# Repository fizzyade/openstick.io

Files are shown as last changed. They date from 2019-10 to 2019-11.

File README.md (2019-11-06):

[uri_license]: https://www.gnu.org/licenses/gpl-3.0.en.html
[uri_license_image]: https://img.shields.io/badge/License-GPLv3-blue.svg

[][uri_license]

# openstick.io
openstick.io is an open source hardware &amp; software project for a USB memory stick.

## About

This project provides an open source hardware design & firmware for a reference implementation of a USB memory stick.  The idea behind this is that extra functionality can be
added to the design, adding encryption, cloning of a stick or more specialised functionality may be added easily.

The actual storage is provided by an on-board Micro SD card, to the host it will look just like a normal memory stick and not a SD card reader.

## Repository Contents

* **/hardware** - KiCad schematic and PCB layout source files.
* **/firmware** - The firmware for the [STM32F070F6Px](https://www.st.com/en/microcontrollers-microprocessors/stm32f070f6.html) microcontroller.

## Required Tools

* **[STM32CubeIDE](https://https://www.st.com/en/development-tools/stm32cubeide.html)** for firmware development.
* **[KiCad](http://kicad-pcb.org/)** for hardware design.

## Project Status

### Hardware

* **Design:** Complete.
* **Manufacture:** In progress.
  * 06-Nov-2019 - PCB's arrived, build and test started.

### Firmware

* **Development:** Started.
  * 06-Nov-2019 - Code based on development board is running correctly, port to actual hardware underway.

## License

This project is open source and the entire project is released under the [GPLv3 license](https://www.gnu.org/licenses/gpl-3.0.en.html).

Distributed as-is; no warranty is given.

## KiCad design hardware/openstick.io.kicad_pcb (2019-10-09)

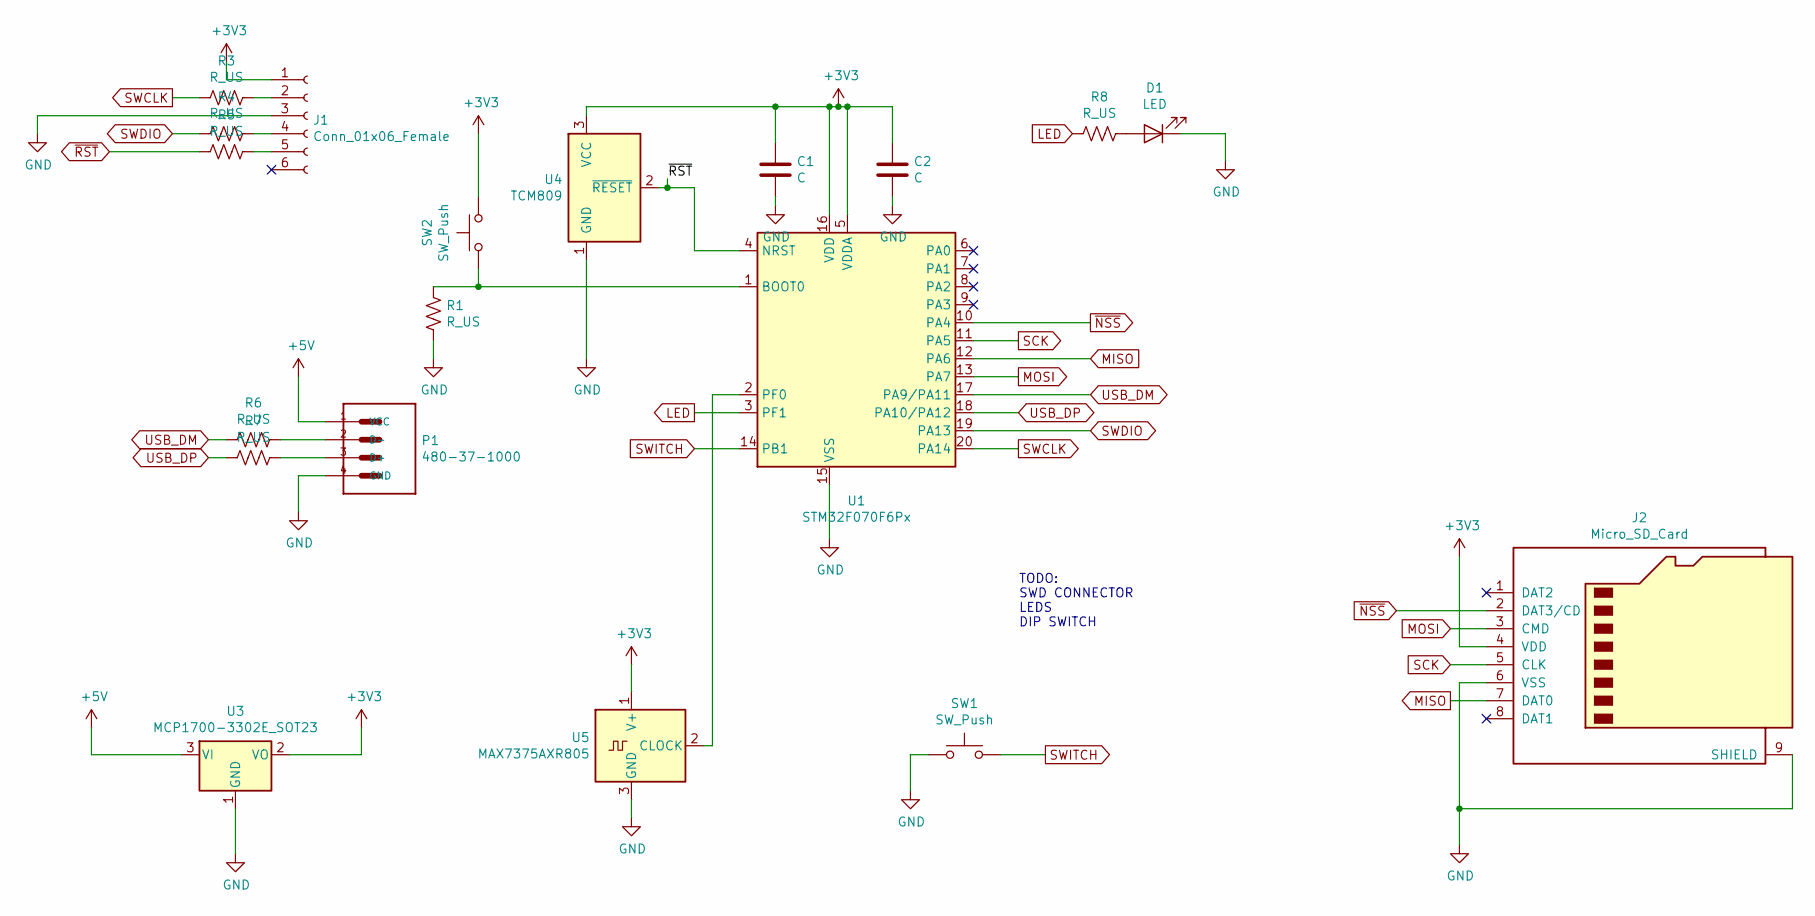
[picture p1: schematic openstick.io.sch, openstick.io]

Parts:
C1, C2: C; C_0805_2012Metric_Pad1.15x1.40mm_HandSolder
D1: LED; LED_0805_2012Metric_Pad1.15x1.40mm_HandSolder
J1: Conn_01x06_Female; PinHeader_1x06_P2.54mm_Vertical
J2: Micro_SD_Card; microSD_HC_Hirose_DM3AT-SF-PEJM5
P1: 480-37-1000; MOLEX_480-37-1000
R1, R3, R4, R5, R6, R7, R8: R_US; R_0805_2012Metric_Pad1.15x1.40mm_HandSolder
SW1, SW2: SW_Push; MP000700
U1: STM32F070F6Px; TSSOP-20_4.4x6.5mm_P0.65mm
U3: MCP1700-3302E_SOT23; SOT-23
U4: TCM809; SOT-23
U5: MAX7375AXR805; SOT-323_SC-70

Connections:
+3V3: C1.1, C2.1, J1.1, J2.4 (VDD), SW2.2, U1.5 (VDDA), U1.16 (VDD), U3.2 (VO), U4.3 (VCC), U5.1 (V+); also elsewhere on the board
+5V: P1.1 (VCC), U3.3 (VI)
LED: R8.2, U1.3 (PF1)
MISO: J2.7 (DAT0), U1.12 (PA6)
MOSI: J2.3 (CMD), U1.13 (PA7)
unnamed: D1.2 (A), R8.1
unnamed: J1.2, R3.1
unnamed: J1.4, R4.1
unnamed: J1.5, R5.1
unnamed: P1.2 (D-), R6.1
unnamed: P1.3 (D+), R7.1
unnamed 14: R1.1, SW2.1, U1.1 (BOOT0); also elsewhere on the board
unnamed: U1.2 (PF0), U5.2 (CLOCK)
SCK: J2.5 (CLK), U1.11 (PA5)
SWCLK: R3.2, U1.20 (PA14)
SWDIO: R4.2, U1.19 (PA13)
SWITCH: SW1.2, U1.14 (PB1)
USB_DM: R6.2, U1.17 (PA9/PA11)
USB_DP: R7.2, U1.18 (PA10/PA12)
~NSS: J2.2 (DAT3/CD), U1.10 (PA4)
~RST: R5.2, U1.4 (NRST), U4.2 (~RESET~)

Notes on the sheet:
TODO: SWD CONNECTOR LEDS DIP SWITCH

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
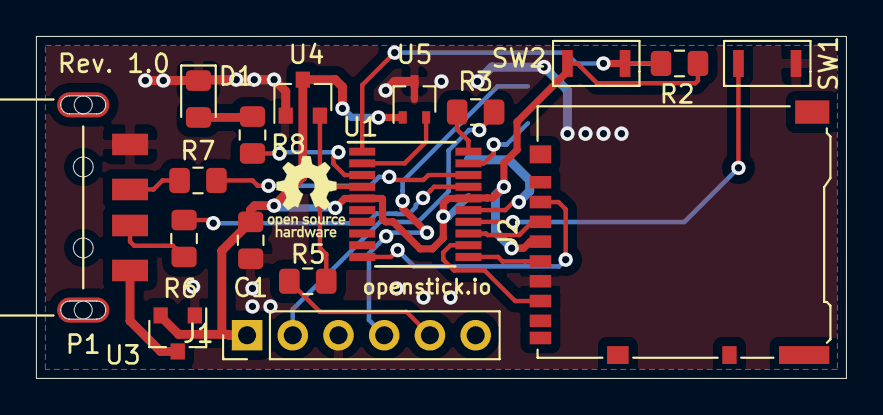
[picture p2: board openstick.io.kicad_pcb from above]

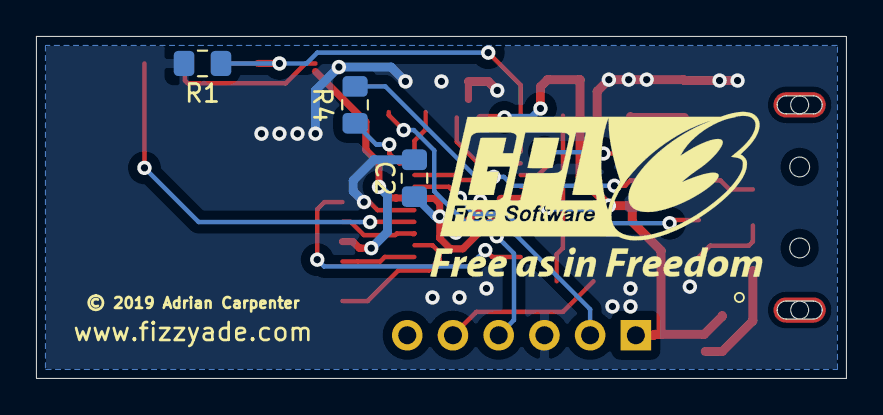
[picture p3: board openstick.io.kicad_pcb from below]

Board: 2 copper layers, 45.0 x 19.0 mm, 20 parts (3 on the bottom side), 22 nets.

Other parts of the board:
R2: R_US; R_0805_2012Metric_Pad1.15x1.40mm_HandSolder

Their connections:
+3V3: R2.1; also elsewhere on the board
unnamed 14: R2.2; also elsewhere on the board

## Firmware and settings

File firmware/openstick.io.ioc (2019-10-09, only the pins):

Mcu.UserName=STM32F070F6Px
PA11.Signal=USB_DM
PA12.Signal=USB_DP
PA13.Signal=SYS_SWDIO
PA14.Signal=SYS_SWCLK
PA2.GPIO_Label=NRST
PA2.Signal=GPIO_Output
PA4.Signal=SPI1_NSS
PA5.Signal=SPI1_SCK
PA6.Signal=SPI1_MISO
PA7.Signal=SPI1_MOSI
PF0-OSC_IN.Signal=RCC_OSC_IN
PF1-OSC_OUT.GPIO_Label=LED
PF1-OSC_OUT.Signal=GPIO_Output

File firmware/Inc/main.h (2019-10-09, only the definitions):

#define LED_Pin GPIO_PIN_1
#define LED_GPIO_Port GPIOF
#define NRST_Pin GPIO_PIN_2
#define NRST_GPIO_Port GPIOA

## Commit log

2019-10-09 repo: initial commit
    [openstick.io.kicad_pcb, openstick.io.sch]
2019-10-10 repo: switched site theme

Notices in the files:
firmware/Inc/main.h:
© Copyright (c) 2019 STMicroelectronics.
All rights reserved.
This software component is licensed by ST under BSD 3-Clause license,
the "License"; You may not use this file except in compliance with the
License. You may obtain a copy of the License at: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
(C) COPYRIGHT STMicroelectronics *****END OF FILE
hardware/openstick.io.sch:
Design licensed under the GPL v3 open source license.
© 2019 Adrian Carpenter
